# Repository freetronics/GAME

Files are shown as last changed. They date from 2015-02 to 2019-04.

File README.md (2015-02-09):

Freetronics Game Controller Shield
==================================
Copyright 2015 Freetronics Pty Ltd  
Freetronics site:  www.freetronics.com  
Freetronics email: info@freetronics.com  

A shield for the Arduino and other microcontroller boards based on the
same header format, such as the Freetronics Eleven. Include a joystick,
buttons, a header for a Freetronics 128x128 Pixel OLED Module, and
a prototyping area.

Safe operation on both 3.3V and 5V Arduino boards.

More information is available on our product page at:

  http://tron.cc/game

INSTALLATION
------------
The design is saved as an EAGLE project. EAGLE PCB design software is
available from www.cadsoftusa.com free for non-commercial use. To use
this project download it and place the directory containing these files
into the "eagle" directory on your computer. Then open EAGLE and
navigate to Projects -> eagle -> GAME.

DISTRIBUTION
------------
The specific terms of distribution of this project are governed by the
license referenced below.

LICENSE
-------
Licensed under the TAPR Open Hardware License (www.tapr.org/OHL).
The "license" folder within this repository also contains a copy of
this license in plain text format.

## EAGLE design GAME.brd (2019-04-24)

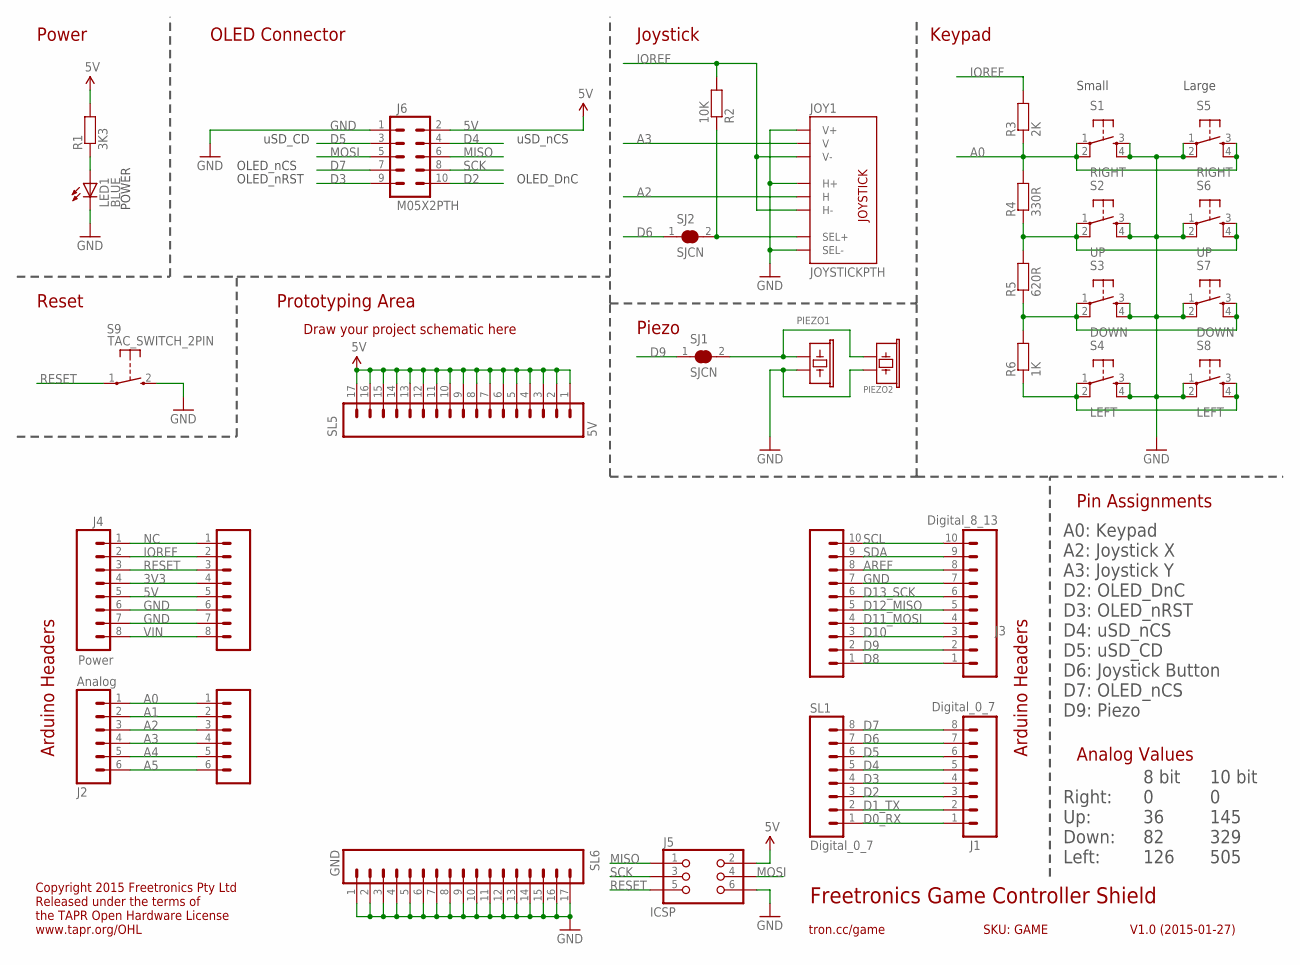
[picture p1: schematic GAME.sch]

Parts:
J1: Digital_0_7; 1X08
J2: Analog; 1X06
J3: Digital_8_13; 1X10
J4: Power; 1X08
J5: ICSP; 2X03PTH
J6: M05X2PTH; AVR_ICSP
JOY1: JOYSTICKPTH; JOYSTICK
LED1: BLUE; LED-0603
PIEZO1: BUZZERSMD12X12; BUZZER-12X12-SMT
PIEZO2: PIEZO12MM
R1: 3K3; 0603
R2: 10K; 0603
R3: 2K; 0603
R4: 330R; 0603
R5: 620R; 0603
R6: 1K; 0603
S1: RIGHT; TACTILE-PTH
S2: UP; TACTILE-PTH
S3: DOWN; TACTILE-PTH
S4: LEFT; TACTILE-PTH
S5: RIGHT; TACTILE-PTH-12MM
S6: UP; TACTILE-PTH-12MM
S7: DOWN; TACTILE-PTH-12MM
S8: LEFT; TACTILE-PTH-12MM
S9: TAC_SWITCH_2PIN; TACTILE_SWITCH_SMD_2PIN_TINY
SJ1, SJ2: SJCN; SJC
SL1: Digital_0_7; 1X08
SL2: Analog; 1X06
SL3: Digital_8_13; 1X10
SL4: Power; 1X08
SL5: 5V; 1X17
SL6: GND; 1X17

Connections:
3V3: J4.4, SL4.4
5V: J4.5, J5.2, J6.2, R1.2, SL4.5, SL5.1, SL5.2, SL5.3, SL5.4, SL5.5, SL5.6, SL5.7, SL5.8, SL5.9, SL5.10, SL5.11, SL5.12, SL5.13, SL5.14, SL5.15, SL5.16, SL5.17
A0: J2.1, R3.1, R4.2, S1.1, S1.2, S5.3, S5.4, SL2.1
A1: J2.2, SL2.2
A2: J2.3, JOY1.H2 (H), SL2.3
A3: J2.4, JOY1.V2 (V), SL2.4
A4: J2.5, SL2.5
A5: J2.6, SL2.6
AREF: J3.8, SL3.8
D0_RX: J1.1, SL1.1
D1_TX: J1.2, SL1.2
D2: J1.3, J6.10, SL1.3
D3: J1.4, J6.9, SL1.4
D4: J1.5, J6.4, SL1.5
D5: J1.6, J6.3, SL1.6
D6: J1.7, SJ2.1, SL1.7
D7: J1.8, J6.7, SL1.8
D8: J3.1, SL3.1
D9: J3.2, SJ1.1, SL3.2
D10: J3.3, SL3.3
D11_MOSI: J3.4, SL3.4
D12_MISO: J3.5, SL3.5
D13_SCK: J3.6, SL3.6
GND: J3.7, J4.6, J4.7, J5.6, J6.1, JOY1.B2A (SEL-), JOY1.H1 (H+), JOY1.V1 (V+), LED1.C, PIEZO1.1, PIEZO2.2, S1.3, S1.4, S2.3, S2.4, S3.3, S3.4, S4.3, S4.4, S5.1, S5.2, S6.1, S6.2, S7.1, S7.2, S8.1, S8.2, S9.2 (S), SL3.7, SL4.6, SL4.7, SL6.1, SL6.2, SL6.3, SL6.4, SL6.5, SL6.6, SL6.7, SL6.8, SL6.9, SL6.10, SL6.11, SL6.12, SL6.13, SL6.14, SL6.15, SL6.16, SL6.17
IOREF: J4.2, JOY1.H3 (H-), JOY1.V3 (V-), R2.2, R3.2, SL4.2
MISO: J5.1, J6.6
MOSI: J5.4, J6.5
unnamed: LED1.A, R1.1
unnamed: PIEZO1.2, PIEZO2.1, SJ1.2
unnamed: JOY1.B1A (SEL+), R2.1, SJ2.2
unnamed: R6.1, S4.1, S4.2, S8.3, S8.4
unnamed: R5.1, R6.2, S3.1, S3.2, S7.3, S7.4
unnamed: R4.1, R5.2, S2.1, S2.2, S6.3, S6.4
NC: J4.1, SL4.1
RESET: J4.3, J5.5, S9.1, SL4.3
SCK: J5.3, J6.8
SCL: J3.10, SL3.10
SDA: J3.9, SL3.9
VIN: J4.8, SL4.8

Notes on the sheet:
Freetronics Game Controller Shield
V1.0 (2015-01-27)
tron.cc/game
SKU: GAME
Arduino Headers
Draw your project schematic here
Copyright 2015 Freetronics Pty Ltd Released under the terms of the TAPR Open Hardware License www.tapr.org/OHL
POWER
OLED_DnC
uSD_CD
OLED_nCS
OLED_nRST
uSD_nCS
Keypad
Joystick
OLED Connector
A0: Keypad A2: Joystick X A3: Joystick Y D2: OLED_DnC D3: OLED_nRST D4: uSD_nCS D5: uSD_CD D6: Joystick Button D7: OLED_nCS D9: Piezo
Power
Reset
Piezo
Prototyping Area
Pin Assignments
10 bit 0 145 329 505
8 bit 0 36 82 126
Right: Up: Down: Left:
Analog Values
Small
Large

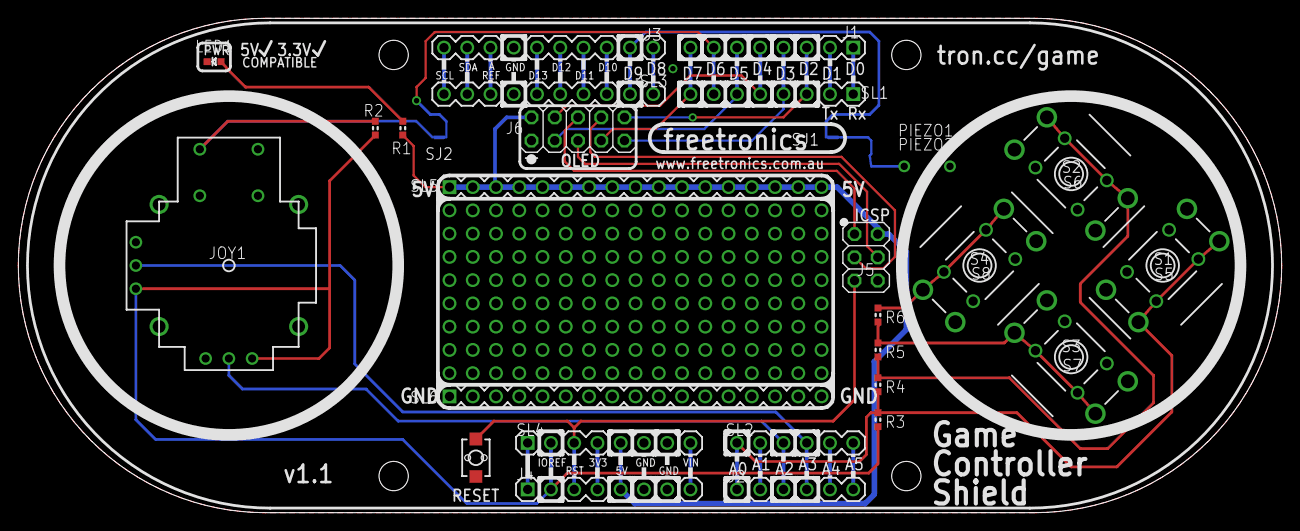
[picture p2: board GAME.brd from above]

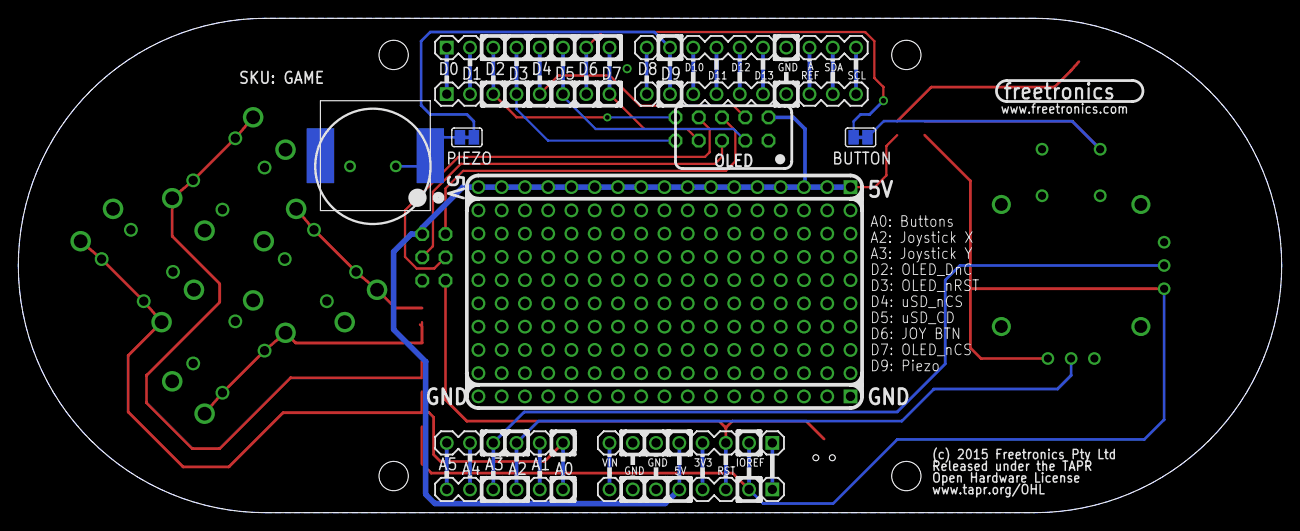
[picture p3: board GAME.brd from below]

Board: 2 copper layers, 138.0 x 54.0 mm, 33 parts (4 on the bottom side), 39 nets.

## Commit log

2015-02-09 Initial project import for v1.0 release
    [GAME.brd, GAME.sch]
2019-04-24 Fixed OLED pinout for v1.1 release
    [GAME.brd, GAME.sch]

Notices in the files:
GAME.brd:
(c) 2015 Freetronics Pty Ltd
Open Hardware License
